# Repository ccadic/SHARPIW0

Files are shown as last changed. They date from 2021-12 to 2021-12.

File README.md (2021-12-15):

# SHARPIW0

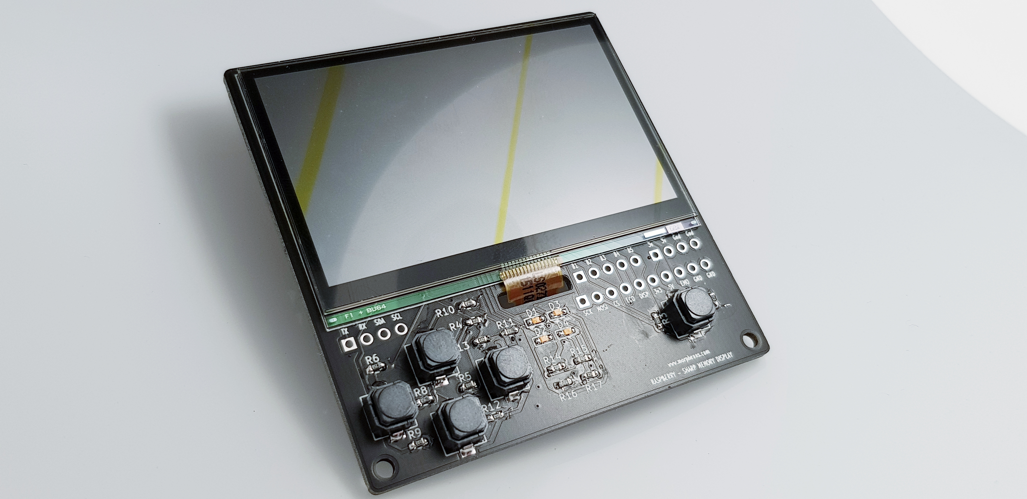
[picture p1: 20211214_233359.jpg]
Sharpiwo


The SHARPIW0 carrier board has been designed to hold both a Raspberry(R) PI ZERO 2W or W + 2.7"  (400x240) Sharp Memory Display. 
This display is capable of a fast refresh which allows the use of linux shells or display game images. 

The board also has 4 independently controlable LEDs you can switch on/off with classic GPIO commands (C++ or Python) 

The board also has 5 buttons you may also control via GPIO voltage detection (UP/Down voltage detection).  You can use this board for gaming.

You can get a fully made board here: https://www.tindie.com/products/electronictrik/sharpiw0-a-rpi-zero-27-sharp-memory-display/ 
It is also a good way to support opensource devices creators

If you need PCB only: https://www.tindie.com/products/electronictrik/sharpiw0-rpi0w-27-sharp-display-pcb-only/

**Extra GPIO available**
 
We added several extra GPIO, should you want to add an external UART extra board or a I2C board.  For the maker, we also added access to the display pins with the right bottom line of 2.54 mm header pinout (SCK to GND). If you want, you can drive the LCD without the Raspberry PI ZERO , and replace it with a classic microcontroller. In the same idea, you have B1 to B5 buttons signals available on pins.

**Installation**
If the board and display come separate, please connect the display's ribbon to the white connector, ribbon contacts facing the board surface. 
Plug the Raspberry PI ZERO like show on the diagram below.

**Software setup**
The Buttons and LEDs are controleable using classic python scripts. 
For the display, you have to install 2 libraries/code and compile them

1° ONE BITE DISPLAY LIB:  https://github.com/bitbank2/OneBitDisplay
Install with git clone https://github.com/bitbank2/OneBitDisplay
Go to /linux/Sharp_LCD directory and type make. 

2° ARMBIANIO LIB: https://github.com/bitbank2/ArmbianIO
Install the lib with git clone https://github.com/bitbank2/ArmbianIO
and make

Go back to Go to /linux/Sharp_LCD directory and  run the compiled executable ./sharp_lcd

Have fun !
Dr CADIC Philippe

Special credits to : Larry Bank for hi precious help and support in this project. 
@fast_code_r_us

Link to new LCD if an accident occurs
Link to SHARP Display: https://fr.aliexpress.com/item/4000674316500.html

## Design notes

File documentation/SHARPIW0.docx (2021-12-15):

SHARPIW0 1.0
RASPBERRY PI ZERO + SHARP LS027B7DH01 MemoryDisplay
Carrier Board

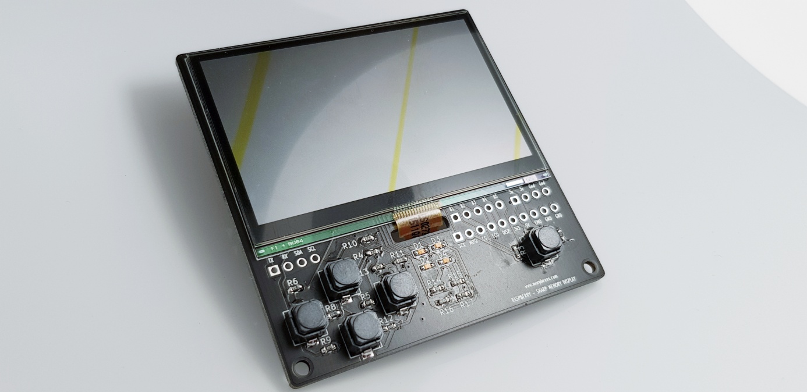
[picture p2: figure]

Description

The SHARPIW0 carrier board has been designed to hold both a Raspberry(R) PI ZERO 2W or W + 2.7" (400x240) Sharp Memory Display. This display is capable of a fast refresh which allows the use of linux shells or display game images.

The board also has 4 independently controlable LEDs you can switch on/off with classic GPIO commands (C++ or Python)

The board also has 5 buttons you may also control via GPIO voltage detection (UP/Down voltage detection). You can use this board for gaming.

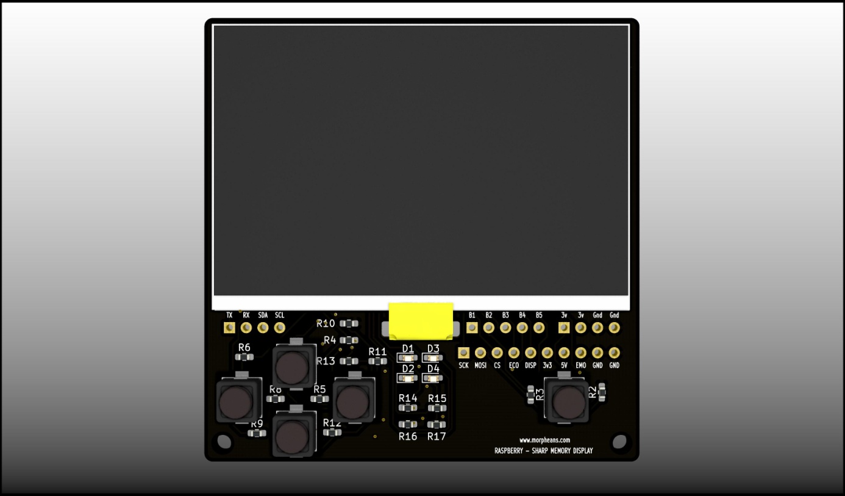
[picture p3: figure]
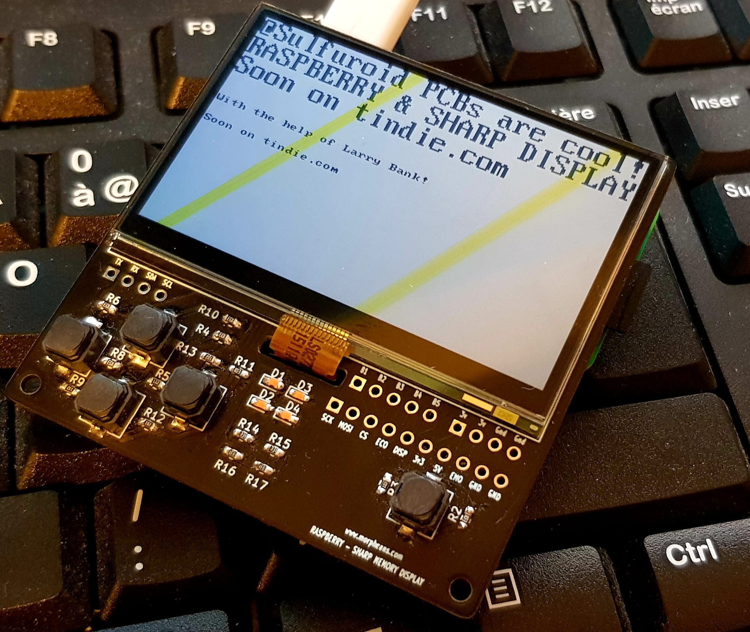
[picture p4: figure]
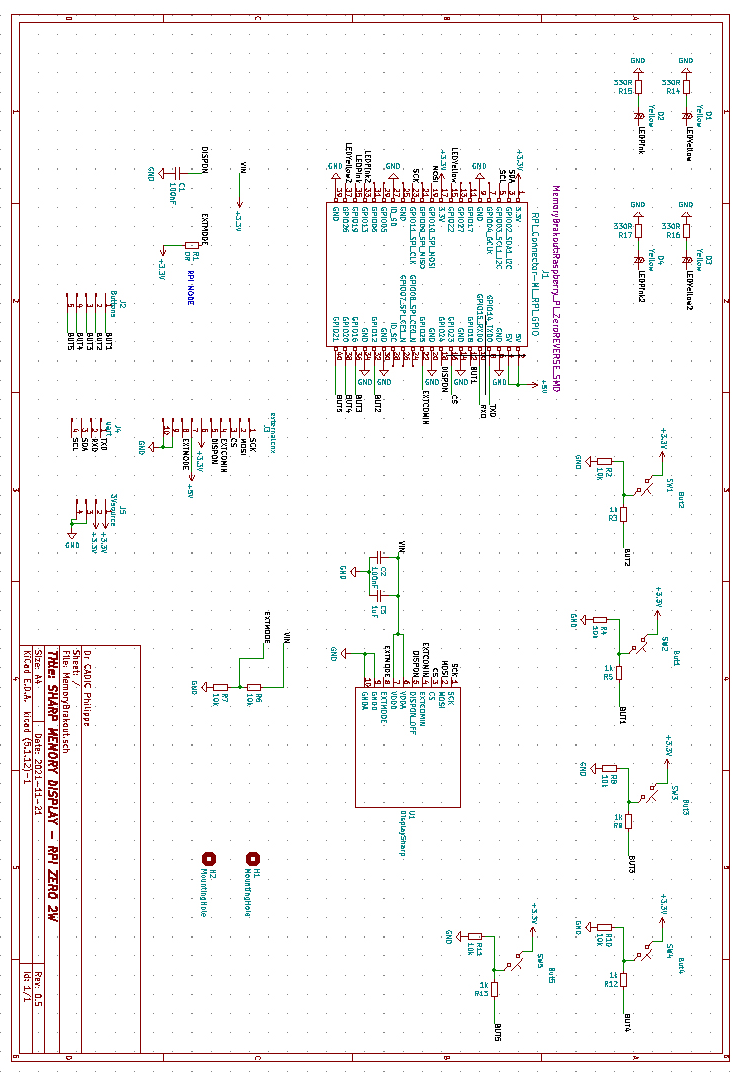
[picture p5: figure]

Extra GPIO available

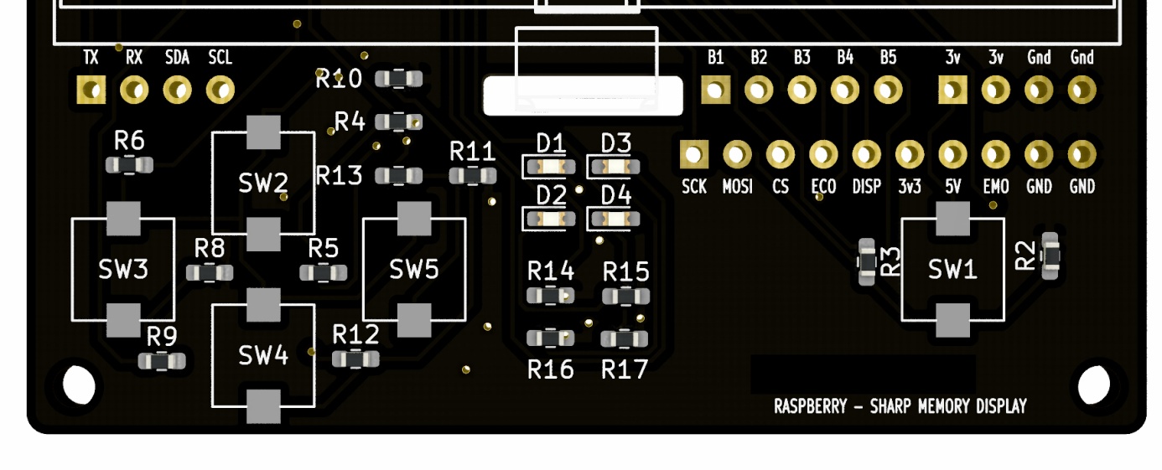
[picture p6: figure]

We added several extra GPIO, should you want to add an external UART extra board or a I2C board. For the maker, we also added access to the display pins with the right bottom line of 2.54 mm header pinout (SCK to GND). If you want, you can drive the LCD without the Raspberry PI ZERO , and replace it with a classic microcontroller. In the same idea, you have B1 to B5 buttons signals available on pins.

Installation

If the board and display come separate, please connect the display's ribbon to the white connector, ribbon contacts facing the board surface.

Plug the Raspberry PI ZERO like show on the diagram below.

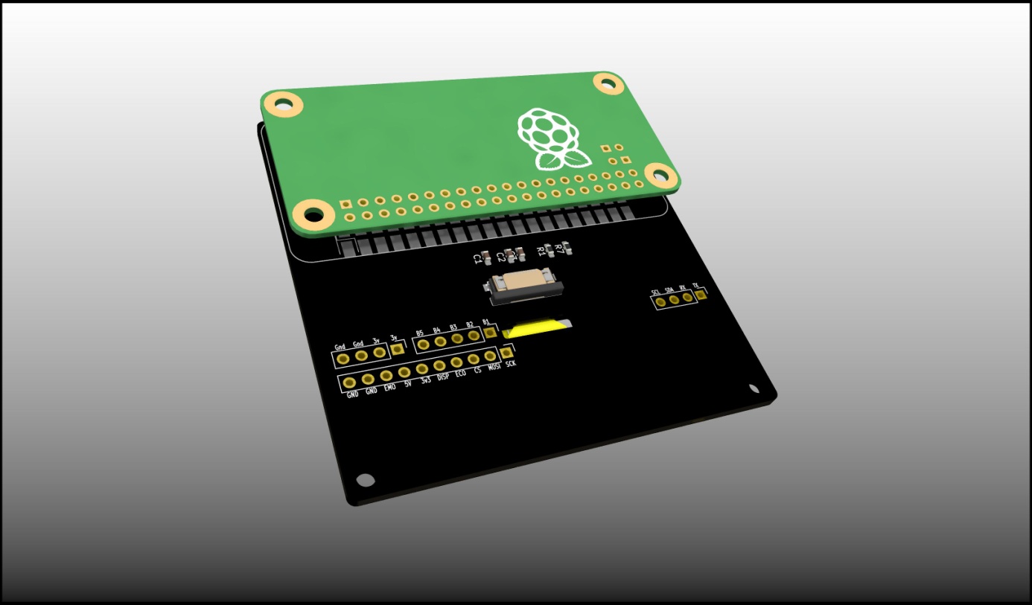
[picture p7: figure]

Software setup

The Buttons and LEDs are controleable using classic python scripts.

For the display, you have to install 2 libraries/code and compile them

1° ONE BITE DISPLAY LIB: https://github.com/bitbank2/OneBitDisplay

Install with git clone https://github.com/bitbank2/OneBitDisplay

Go to /linux/Sharp_LCD directory and type make.

2° ARMBIANIO LIB: https://github.com/bitbank2/ArmbianIO

Install the lib with git clone https://github.com/bitbank2/ArmbianIO

and make

Go back to Go to /linux/Sharp_LCD directory and run the compiled executable ./sharp_lcd

Have fun !

Dr CADIC Philippe

Special credits to : Larry Bank for hi precious help and support in this project.
@fast_code_r_us

Link to new LCD if an accident occurs

Link to SHARP Display: https://fr.aliexpress.com/item/4000674316500.html

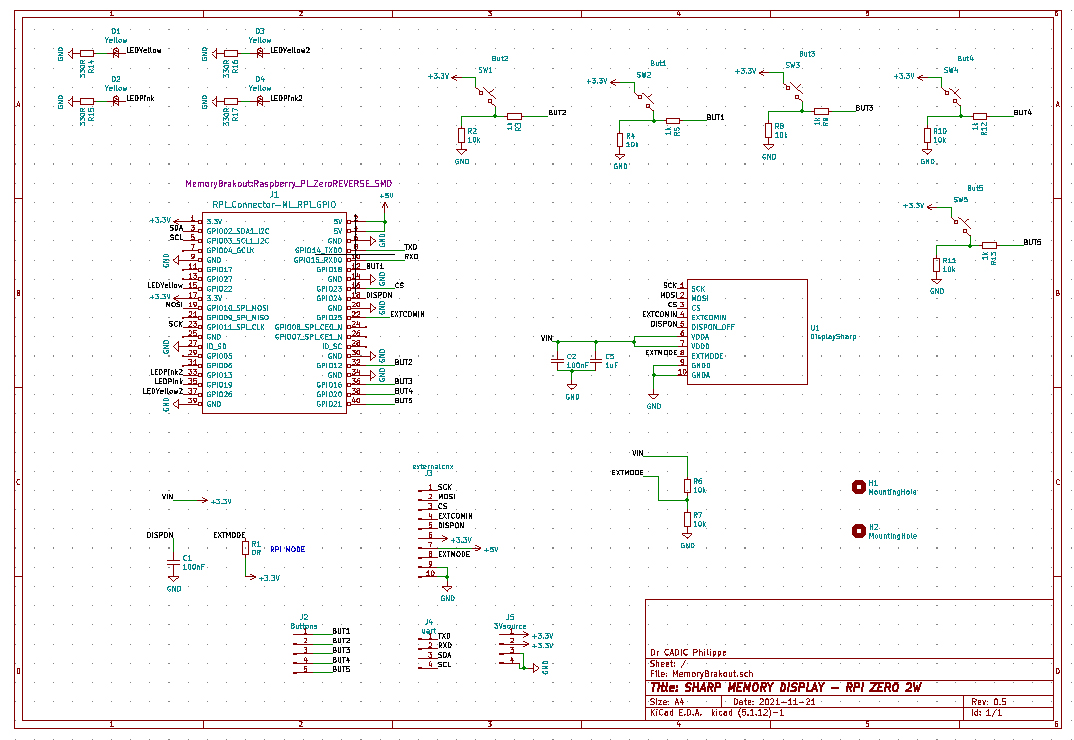
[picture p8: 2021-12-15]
schemartic1.jpg

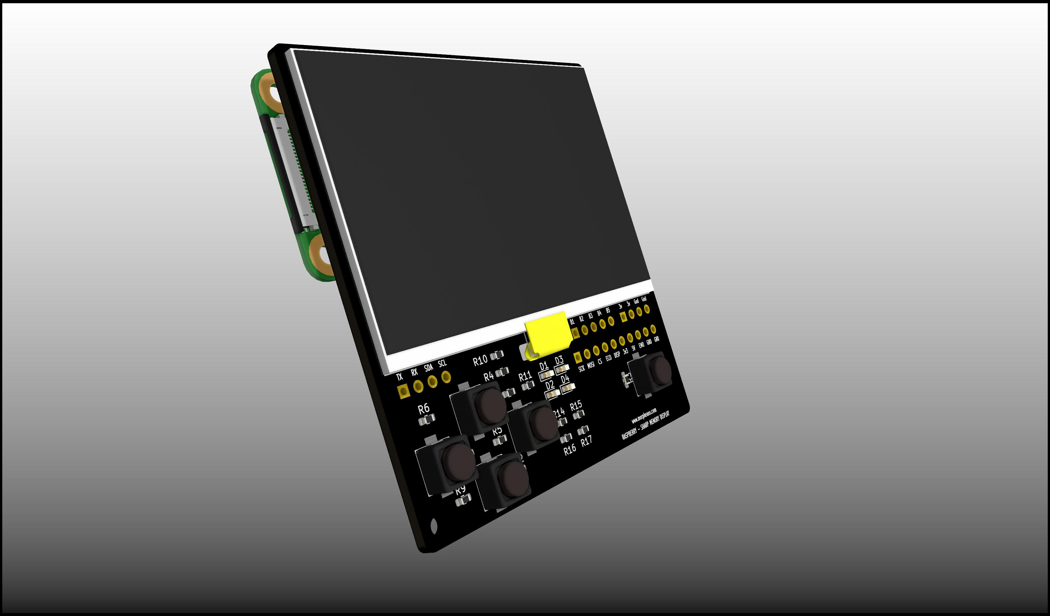
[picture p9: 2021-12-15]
MemoryBrakout.jpg

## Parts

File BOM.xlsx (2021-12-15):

Reference | Value | Footprint | URL
U1 | DisplaySharp | MemoryBrakout:SHARP27LCD | https://fr.aliexpress.com/item/4000674316500.html
J1 | RPI_Connector-ML_RPi_GPIO | MemoryBrakout:Raspberry_Pi_ZeroREVERSE_SMD | 20x2 2.54 header pin (female)
R6 | 10k | Resistor_SMD:R_0603_1608Metric_Pad0.98x0.95mm_HandSolder
R7 | 10k | Resistor_SMD:R_0603_1608Metric_Pad0.98x0.95mm_HandSolder
C1 | 100nF | Capacitor_SMD:C_0603_1608Metric_Pad1.08x0.95mm_HandSolder
C2 | 100nF | Capacitor_SMD:C_0603_1608Metric_Pad1.08x0.95mm_HandSolder
C3 | 1uF | Capacitor_SMD:C_0603_1608Metric_Pad1.08x0.95mm_HandSolder
R1 | 0R | Resistor_SMD:R_0603_1608Metric_Pad0.98x0.95mm_HandSolder
R4 | 10k | Resistor_SMD:R_0603_1608Metric_Pad0.98x0.95mm_HandSolder
R5 | 1k | Resistor_SMD:R_0603_1608Metric_Pad0.98x0.95mm_HandSolder
SW2 | But1 | 18650:SW_TP1003 | https://fr.aliexpress.com/item/32820232659.html
R2 | 10k | Resistor_SMD:R_0603_1608Metric_Pad0.98x0.95mm_HandSolder
R3 | 1k | Resistor_SMD:R_0603_1608Metric_Pad0.98x0.95mm_HandSolder
SW1 | But2 | 18650:SW_TP1003
R10 | 10k | Resistor_SMD:R_0603_1608Metric_Pad0.98x0.95mm_HandSolder
R12 | 1k | Resistor_SMD:R_0603_1608Metric_Pad0.98x0.95mm_HandSolder
SW4 | But4 | 18650:SW_TP1003
R8 | 10k | Resistor_SMD:R_0603_1608Metric_Pad0.98x0.95mm_HandSolder
R9 | 1k | Resistor_SMD:R_0603_1608Metric_Pad0.98x0.95mm_HandSolder
SW3 | But3 | 18650:SW_TP1003
R11 | 10k | Resistor_SMD:R_0603_1608Metric_Pad0.98x0.95mm_HandSolder
R13 | 1k | Resistor_SMD:R_0603_1608Metric_Pad0.98x0.95mm_HandSolder
SW5 | But5 | 18650:SW_TP1003
J2 | Buttons | Connector_PinHeader_2.54mm:PinHeader_1x05_P2.54mm_Vertical
R14 | 330R | Resistor_SMD:R_0603_1608Metric_Pad0.98x0.95mm_HandSolder
D1 | Yellow | LED_SMD:LED_0603_1608Metric_Castellated
R15 | 330R | Resistor_SMD:R_0603_1608Metric_Pad0.98x0.95mm_HandSolder
D2 | Yellow | LED_SMD:LED_0603_1608Metric_Castellated
R16 | 330R | Resistor_SMD:R_0603_1608Metric_Pad0.98x0.95mm_HandSolder
D3 | Yellow | LED_SMD:LED_0603_1608Metric_Castellated
R17 | 330R | Resistor_SMD:R_0603_1608Metric_Pad0.98x0.95mm_HandSolder
D4 | Yellow | LED_SMD:LED_0603_1608Metric_Castellated

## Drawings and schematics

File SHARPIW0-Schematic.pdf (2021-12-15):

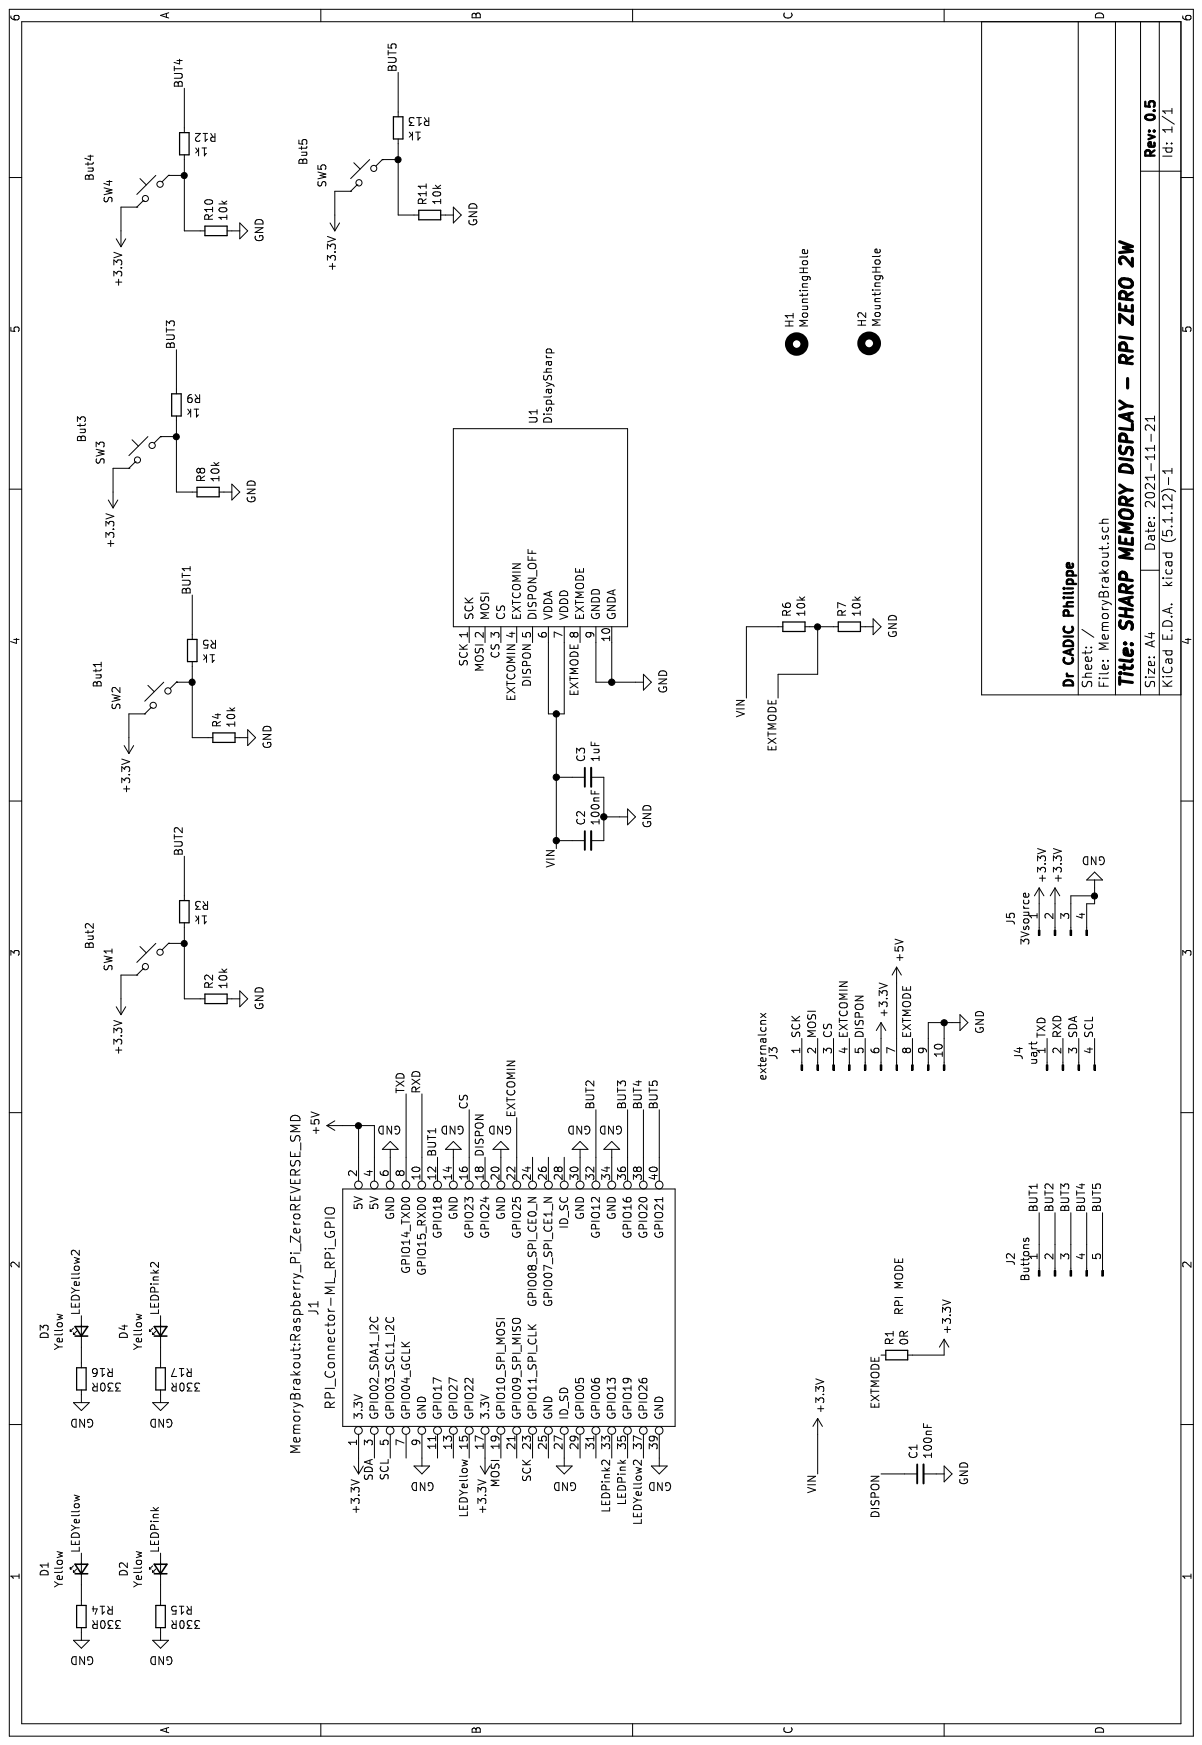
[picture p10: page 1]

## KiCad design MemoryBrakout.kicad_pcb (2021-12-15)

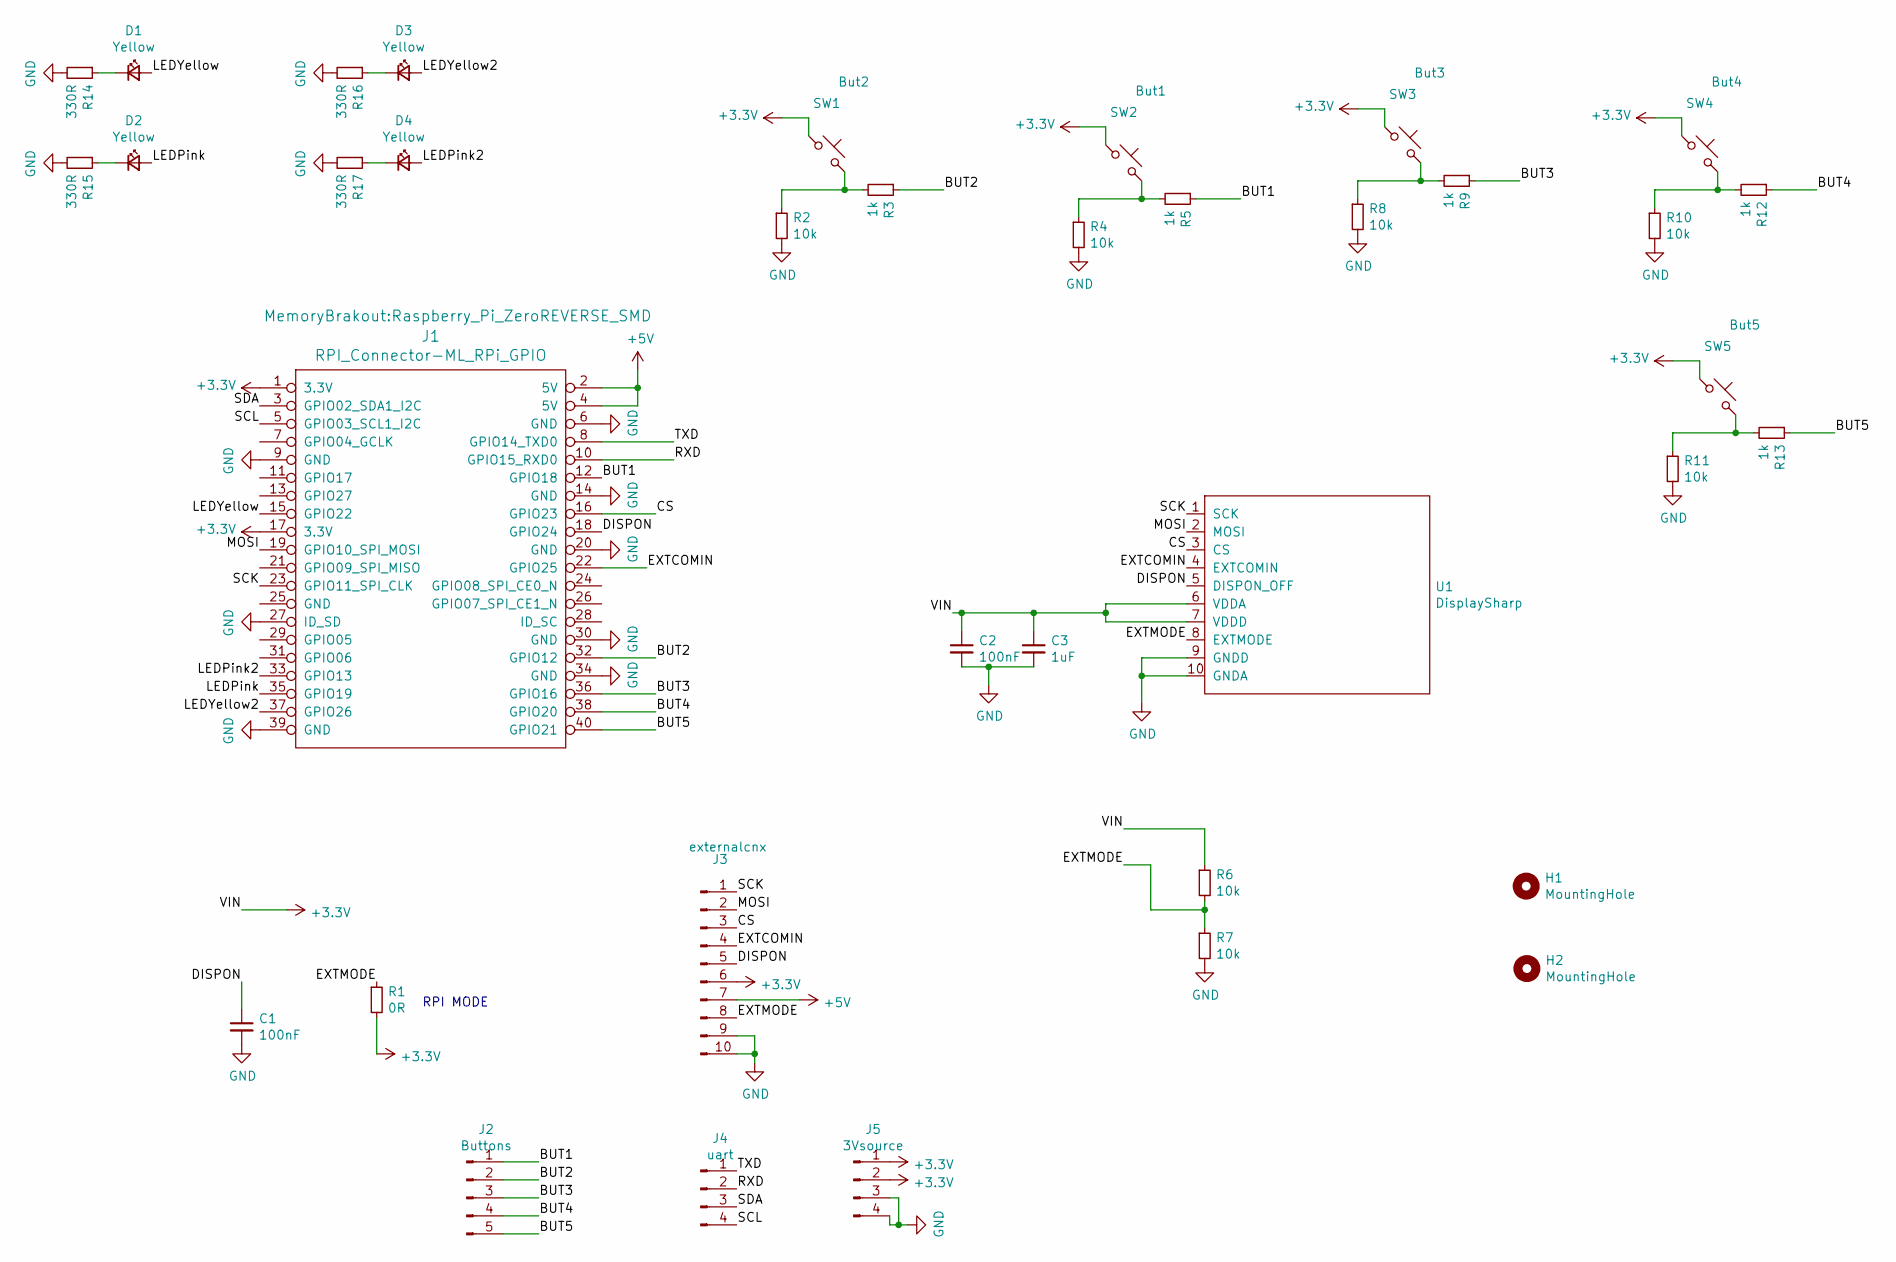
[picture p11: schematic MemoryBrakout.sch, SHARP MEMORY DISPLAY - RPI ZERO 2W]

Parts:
C1, C2: 100nF; C_0603_1608Metric_Pad1.08x0.95mm_HandSolder
C3: 1uF; C_0603_1608Metric_Pad1.08x0.95mm_HandSolder
D1, D2, D3, D4: Yellow; LED_0603_1608Metric_Castellated
H1, H2: MountingHole; MountingHole_2.5mm
J1: RPI_Connector-ML_RPi_GPIO; Raspberry_Pi_ZeroREVERSE_SMD
J2: Buttons; PinHeader_1x05_P2.54mm_Vertical
J3: externalcnx; PinHeader_1x10_P2.54mm_Vertical
J4: uart; PinHeader_1x04_P2.54mm_Vertical
J5: 3Vsource; PinHeader_1x04_P2.54mm_Vertical
R1: 0R; R_0603_1608Metric_Pad0.98x0.95mm_HandSolder
R2, R4, R6, R7, R8, R10, R11: 10k; R_0603_1608Metric_Pad0.98x0.95mm_HandSolder
R3, R5, R9, R12, R13: 1k; R_0603_1608Metric_Pad0.98x0.95mm_HandSolder
R14, R15, R16, R17: 330R; R_0603_1608Metric_Pad0.98x0.95mm_HandSolder
SW1: But2; SW_TP1003
SW2: But1; SW_TP1003
SW3: But3; SW_TP1003
SW4: But4; SW_TP1003
SW5: But5; SW_TP1003
U1: DisplaySharp; SHARP27LCD

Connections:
+3V3: C2.1, C3.1, J1.1 (3.3V), J1.17 (3.3V), J3.6, J5.1, J5.2, R1.2, R6.1, SW1.1, SW2.1, SW3.1, SW4.1, SW5.1, U1.6 (VDDA), U1.7 (VDDD)
+5V: J1.2 (5V), J1.4 (5V), J3.7
/BUT1: J1.12 (GPIO18), J2.1, R5.1
/BUT2: J1.32 (GPIO12), J2.2, R3.1
/BUT3: J1.36 (GPIO16), J2.3, R9.1
/BUT4: J1.38 (GPIO20), J2.4, R12.1
/BUT5: J1.40 (GPIO21), J2.5, R13.1
/CS: J1.16 (GPIO23), J3.3, U1.3 (CS)
/DISPON: C1.1, J1.18 (GPIO24), J3.5, U1.5 (DISPON_OFF)
/EXTCOMIN: J1.22 (GPIO25), J3.4, U1.4 (EXTCOMIN)
/EXTMODE: J3.8, R1.1, R6.2, R7.1, U1.8 (EXTMODE)
/LEDPink: D2.2 (A), J1.35 (GPIO19)
/LEDPink2: D4.2 (A), J1.33 (GPIO13)
/LEDYellow: D1.2 (A), J1.15 (GPIO22)
/LEDYellow2: D3.2 (A), J1.37 (GPIO26)
/MOSI: J1.19 (GPIO10_SPI_MOSI), J3.2, U1.2 (MOSI)
/RXD: J1.10 (GPIO15_RXD0), J4.2
/SCK: J1.23 (GPIO11_SPI_CLK), J3.1, U1.1 (SCK)
/SCL: J1.5 (GPIO03_SCL1_I2C), J4.4
/SDA: J1.3 (GPIO02_SDA1_I2C), J4.3
/TXD: J1.8 (GPIO14_TXD0), J4.1
GND: C1.2, C2.2, C3.2, J1.6 (GND), J1.9 (GND), J1.14 (GND), J1.20 (GND), J1.27 (ID_SD), J1.30 (GND), J1.34 (GND), J1.39 (GND), J3.9, J3.10, J5.3, J5.4, R2.2, R4.2, R7.2, R8.2, R10.2, R11.2, R14.2, R15.2, R16.2, R17.2, U1.9 (GNDD), U1.10 (GNDA)
unnamed: D1.1 (K), R14.1
unnamed: D2.1 (K), R15.1
unnamed: D3.1 (K), R16.1
unnamed: D4.1 (K), R17.1
unnamed: R2.1, R3.2, SW1.2
unnamed: R4.1, R5.2, SW2.2
unnamed: R8.1, R9.2, SW3.2
unnamed: R10.1, R12.2, SW4.2
unnamed: R11.1, R13.2, SW5.2

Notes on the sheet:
RPI MODE

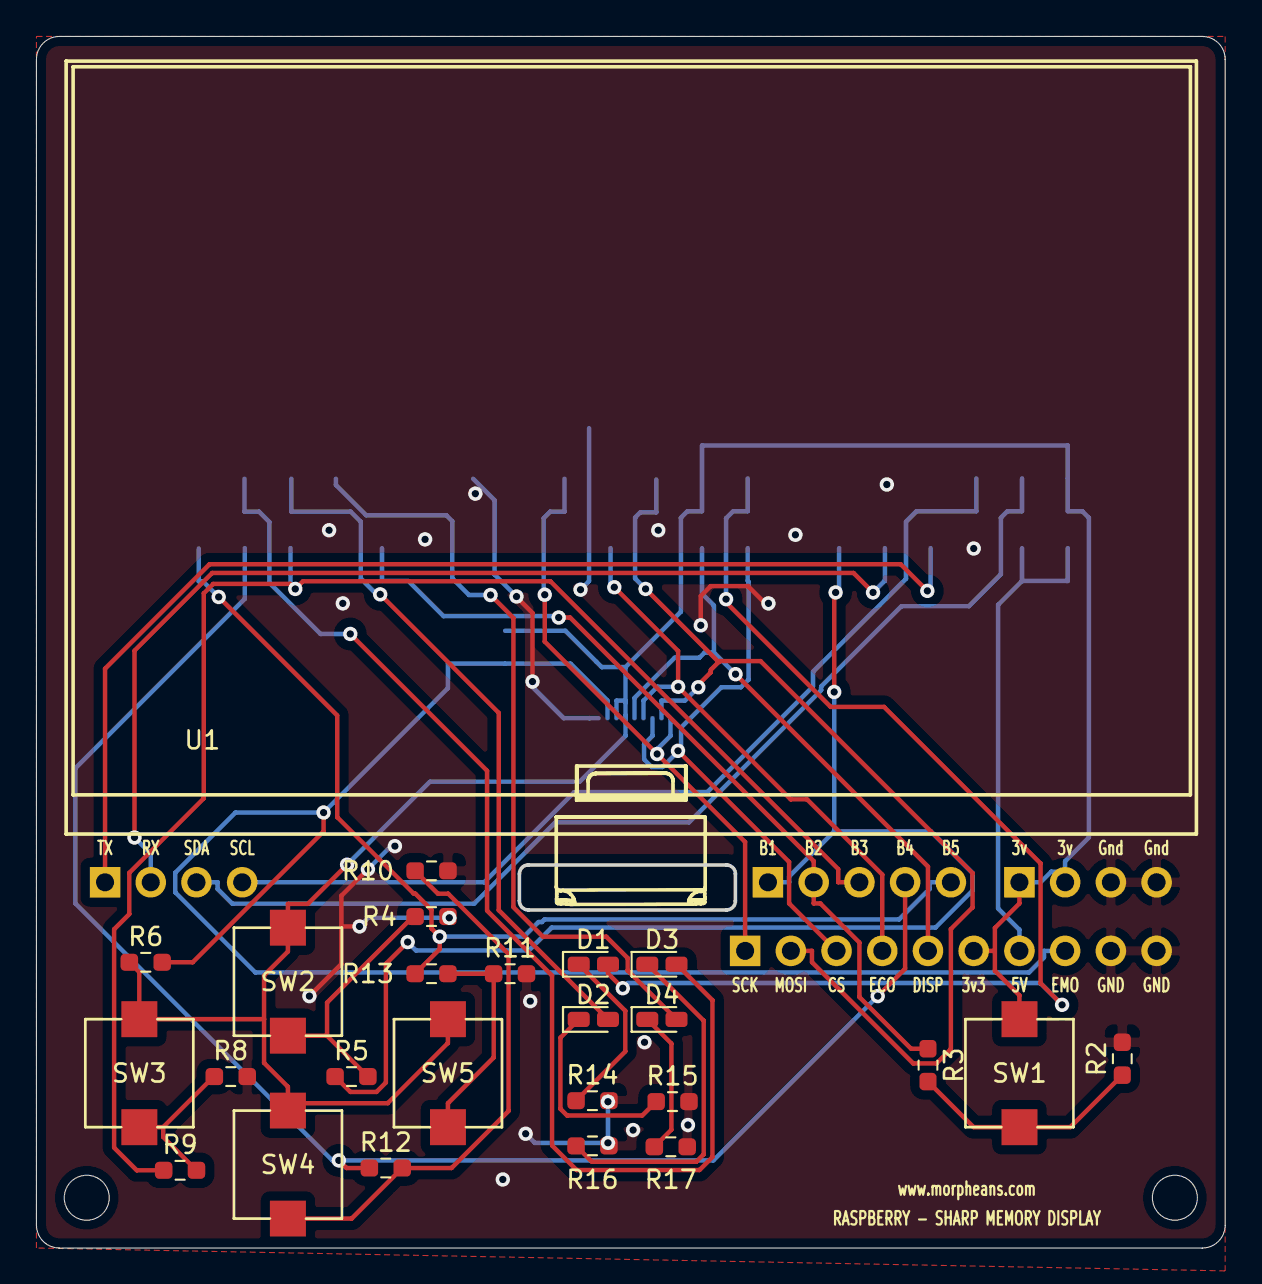
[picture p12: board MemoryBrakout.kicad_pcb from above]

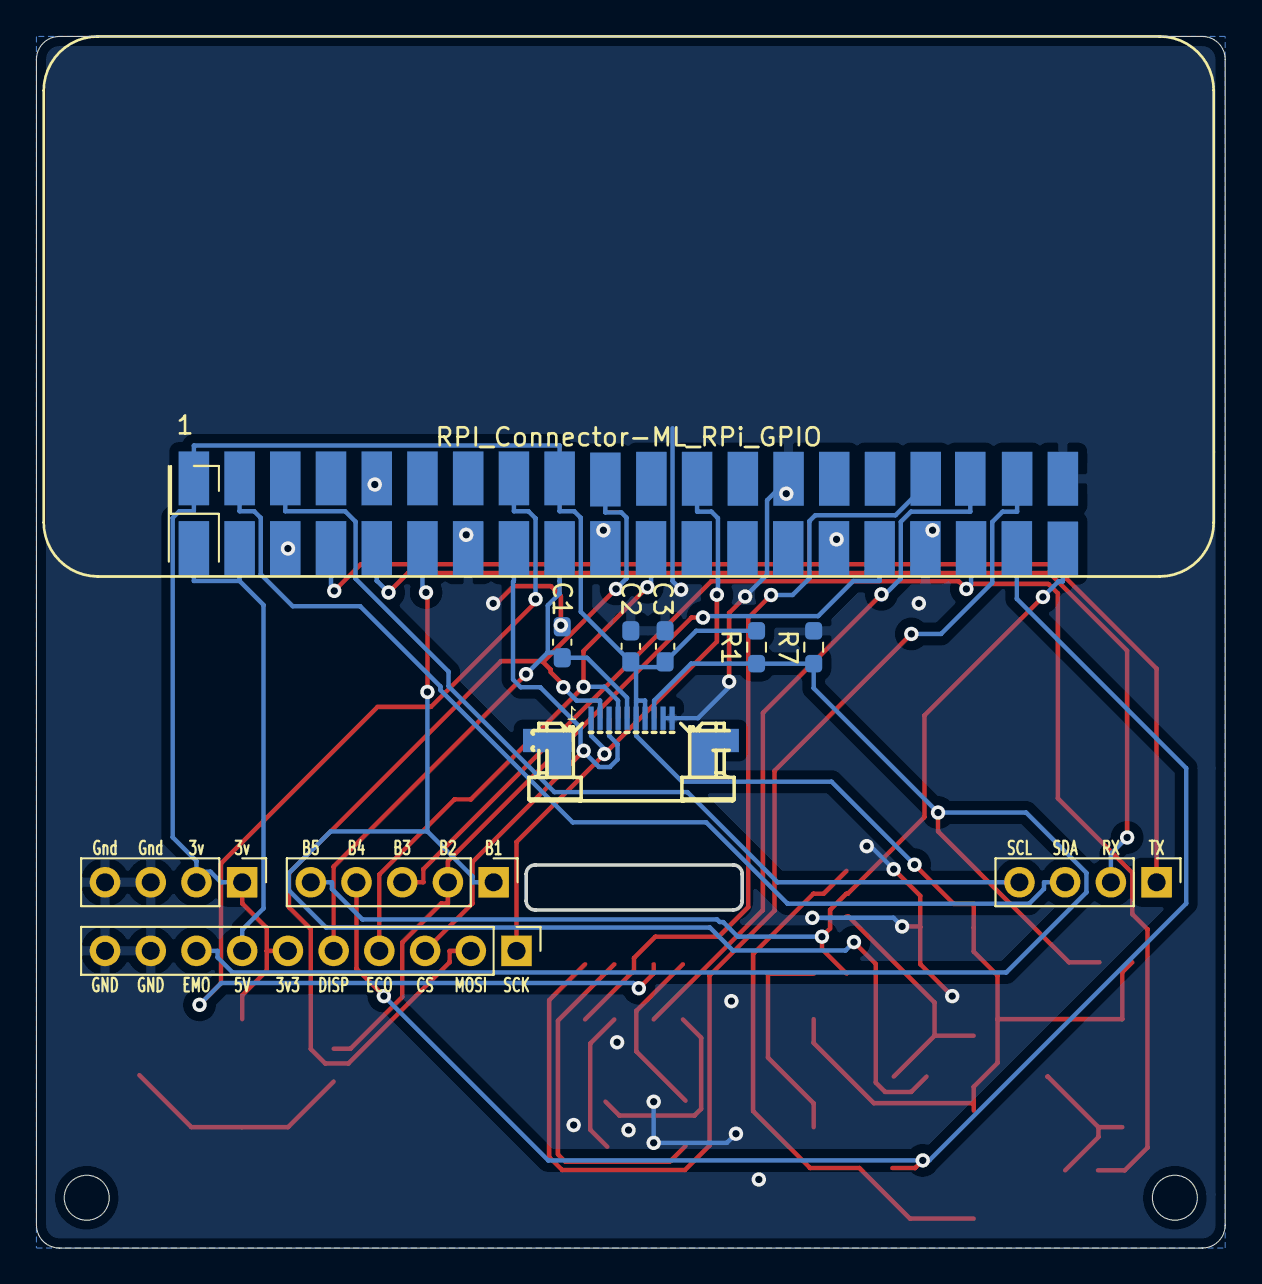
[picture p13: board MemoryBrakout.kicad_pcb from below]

Board: 2 copper layers, 66.0 x 67.3 mm, 37 parts (10 on the bottom side), 31 nets.

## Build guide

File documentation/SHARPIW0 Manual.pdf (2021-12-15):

# SHARPIW0 1.0

RASPBERRY PI ZERO + SHARP LS027B7DH01 MemoryDisplay Carrier Board

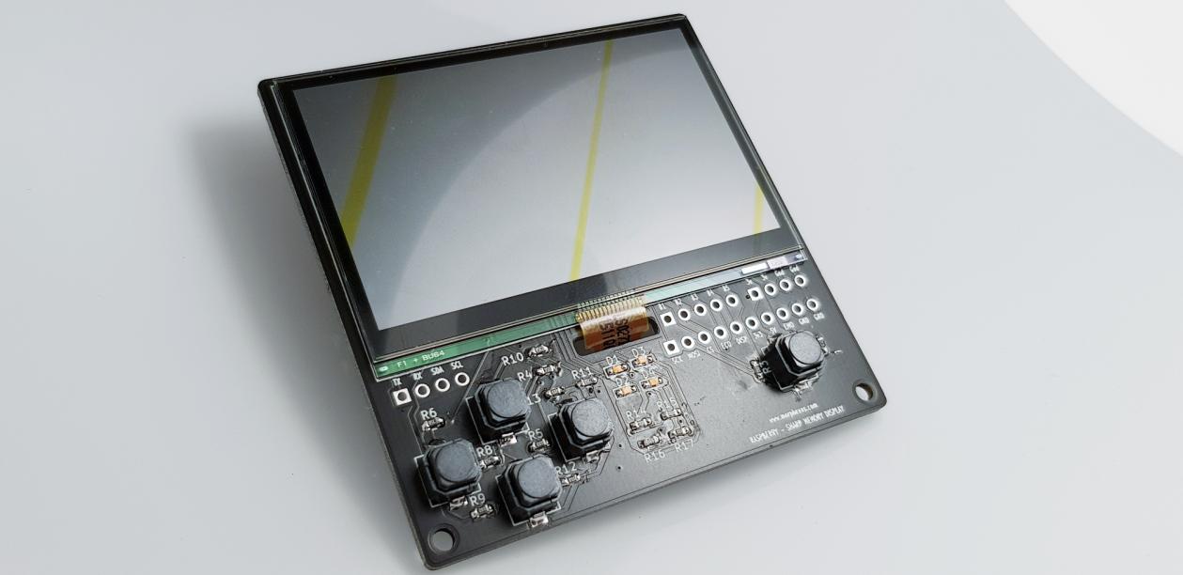
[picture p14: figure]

Description

The SHARPIW0 carrier board has been designed to hold both a Raspberry(R) PI ZERO 2W or W + 2.7" (400x240) Sharp Memory Display. This display is capable of a fast refresh which allows the use of linux shells or display game images.

The board also has 4 independently controlable LEDs you can switch on/off with classic GPIO commands (C++ or Python)

The board also has 5 buttons you may also control via GPIO voltage detection (UP/Down voltage detection). You can use this board for gaming.

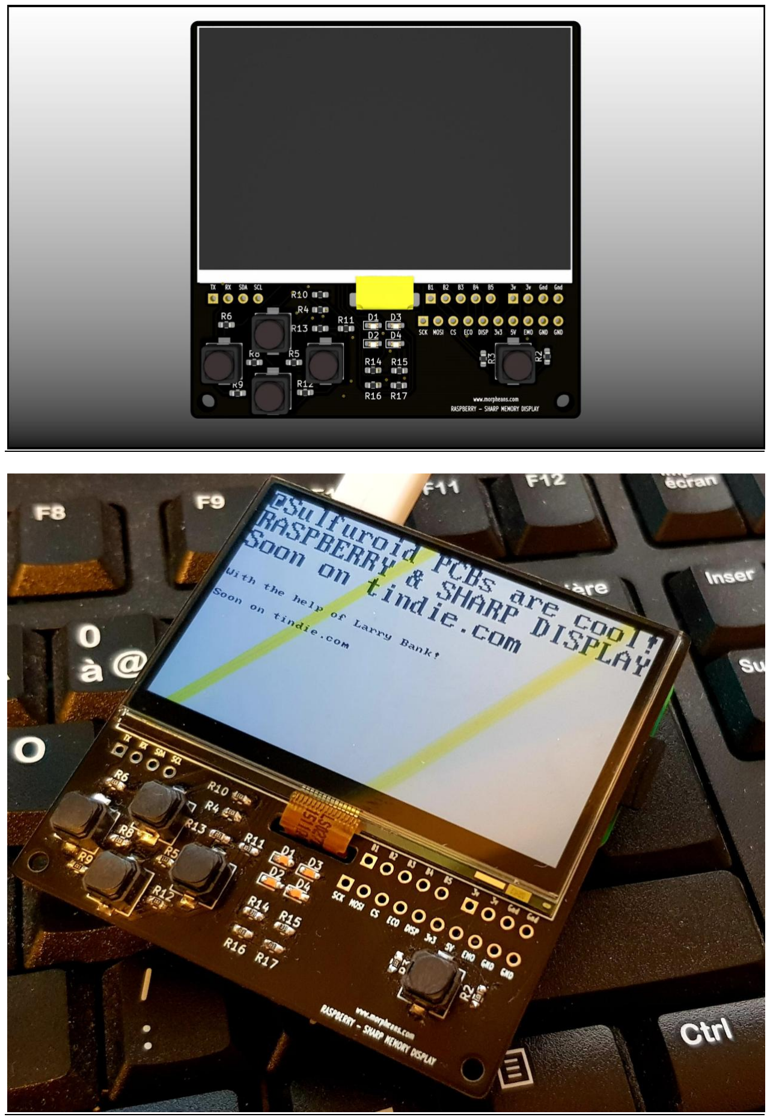
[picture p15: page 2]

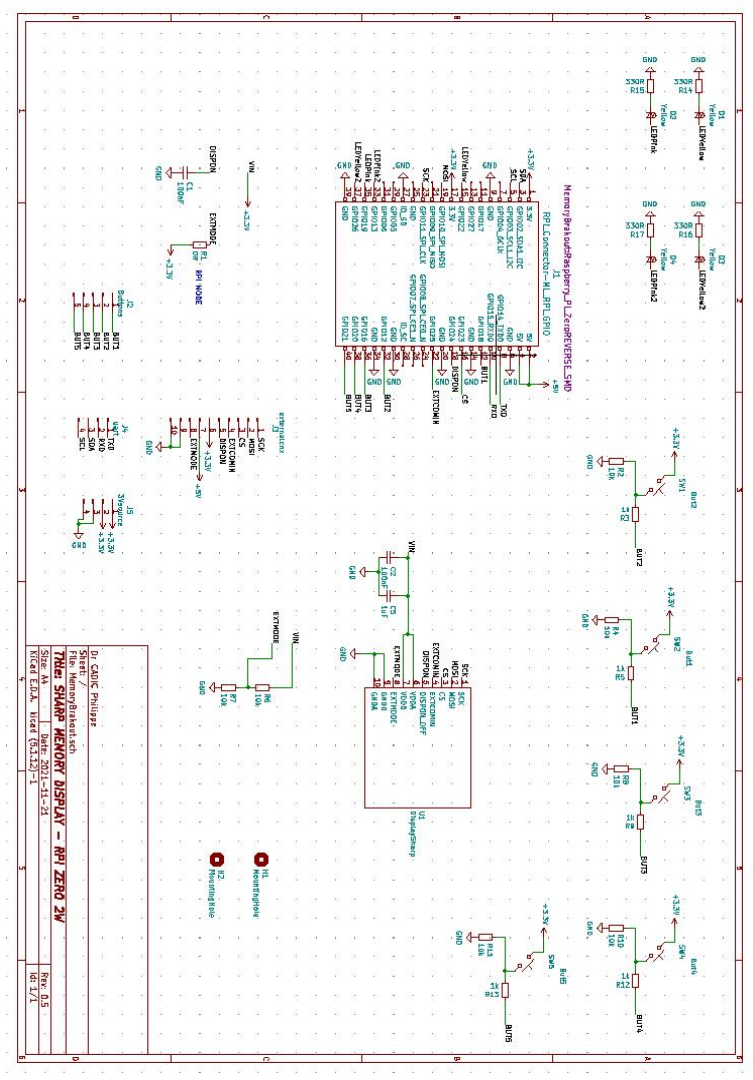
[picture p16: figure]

Extra GPIO available

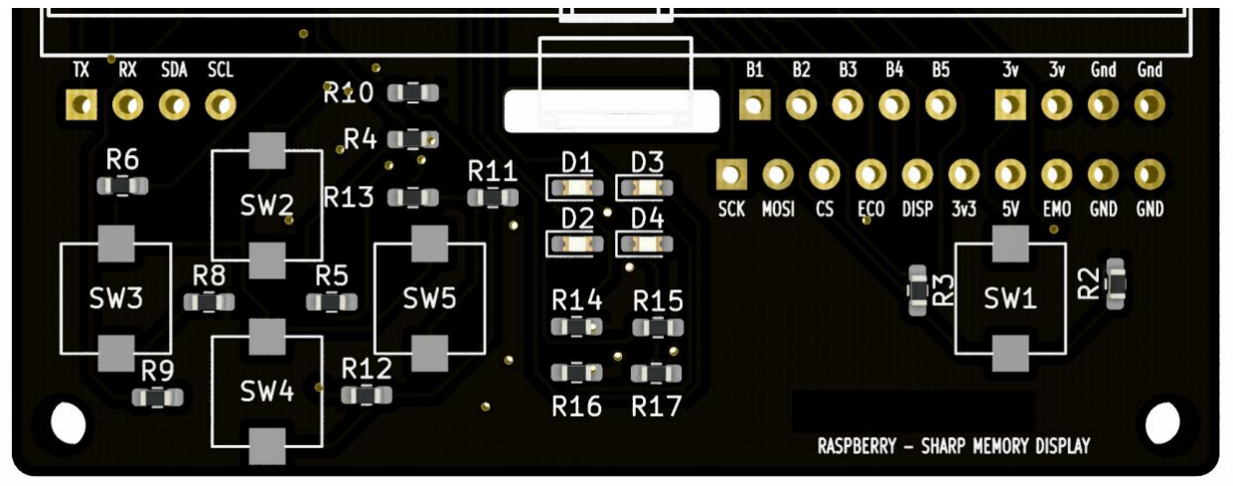
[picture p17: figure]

We added several extra GPIO, should you want to add an external UART extra board or a I2C board. For the maker, we also added access to the display pins with the right bottom line of 2.54 mm header pinout (SCK to GND). If you want, you can drive the LCD without the Raspberry PI ZERO , and replace it with a classic microcontroller. In the same idea, you have B1 to B5 buttons signals available on pins.

Installation

If the board and display come separate, please connect the display's ribbon to the white connector, ribbon contacts facing the board surface.

Plug the Raspberry PI ZERO like show on the diagram below.

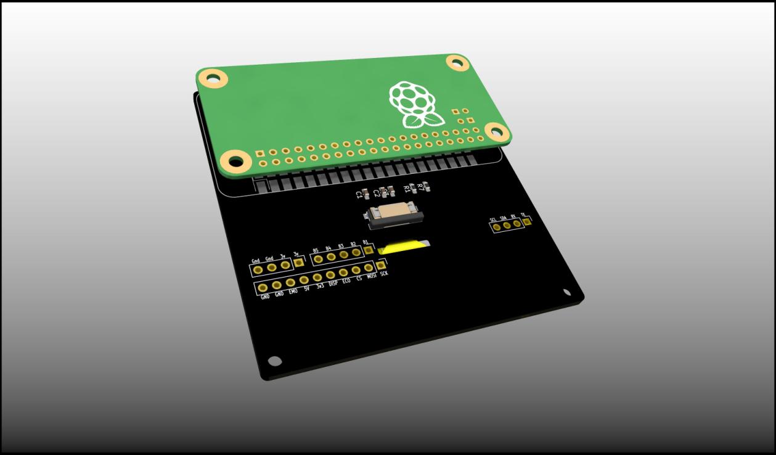
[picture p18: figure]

Software setup

The Buttons and LEDs are controleable using classic python scripts.

For the display, you have to install 2 libraries/code and compile them

1° ONE BITE DISPLAY LIB: https://github.com/bitbank2/OneBitDisplay

Install with git clone https://github.com/bitbank2/OneBitDisplay

Go to /linux/Sharp_LCD directory and type make.

2° ARMBIANIO LIB: https://github.com/bitbank2/ArmbianIO

Install the lib with git clone https://github.com/bitbank2/ArmbianIO

and make

Go back to Go to /linux/Sharp_LCD directory and run the compiled executable ./sharp_lcd

Have fun !

Dr CADIC Philippe

Special credits to : Larry Bank for hi precious help and support in this project. @fast_code_r_us

Link to new LCD if an accident occurs

Link to SHARP Display: https://fr.aliexpress.com/item/4000674316500.html
